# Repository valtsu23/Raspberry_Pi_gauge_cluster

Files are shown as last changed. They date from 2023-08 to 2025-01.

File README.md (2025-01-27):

# Raspberry_Pi_gauge_cluster
### Check out also new improved version: https://github.com/valtsu23/DIY-Emu-Black-Dash



Video: https://youtu.be/ISC5q4k9wDg

### Updates
30.8.2023 display_v2.py released (more info on the file)

### How it works
Adafruit Feather receives messages from Can Bus and picks rpm signal for shift light. Feather sends same can bus data bytes over Uart to Raspberry pi. 
Feather reads the amount of ambient light from photodiode and controls screeen brightness with pwm. 
Device needs switched 12V and continous 12v from battery to work correctly. Switched power wakes up the device and Raspberry pi starts booting. When Can Bus stream is lost Raspberry pi automatically starts shutdown process and sends message to Feather. After specified time the Feather turns off the relay connected to continous 12v and cuts power from the device. The device doesn't consume any power after shutdown. 

### Something to improve
- More testing needed
- Adding Raspberry pi setup guide
- Shortening the start up time (about 25 seconds now)

### Technical specs:
- Raspberry Pi 4 Model B 4GB
- SanDisk Extreme Pro UHS-I U3 64GB microSD
- 5" sunlight readable display with touchscreen from Makerplane:
  - https://store.makerplane.org/5-sunlight-readable-touchscreen-hdmi-display-for-raspberry-pi/
- DIY PCB inside the enclosure controls power for all devices and receives Can Bus messages and sends them over UART to Raspberry pi
  - DC-DC converter
  - Adafruit Feather M4 CAN Express with ATSAME51
  - Adafruit DS3231 Precision RTC - STEMMA QT
  - Screen brightness control
  - Adafruit Neopixel shiftlight control
  - Small relay for power

### Software specs
- Raspberry Pi OS Lite 64bit (bullseye)
  - X server: X.Org
  - Window manager: Openbox
  - Gauge cluster software is based on Pygame graphics library
### Graphic software functions
- There is 6 sensors data (3 left and 3 right) that you can choose to display with touscreen
- bar on the bottom of the screen in normal situation is blue and shows Raspberry pi CPU temperature
- If there is some error detected by ECU or battery voltage is low. Error flags are shown on the bottom of the screen and the bar is red
  
### Can bus data
- Most of the data needed is read from Ecumaster Emu Black can stream
- There is also DIY can bus device sending message id 0x400, which contains
  - Turn signals
  - High beam on
  - Fuel level
  - Ambient temperature

### Case
- Designed with FreeCAD
- Filament is PETG
- M3x6 machine screws 2 pcs
- M4 thread insert 1 pcs
- M4x8 machine screw 1pcs
- M4x20 machine screw 2pcs
- M4 nut 2pcs

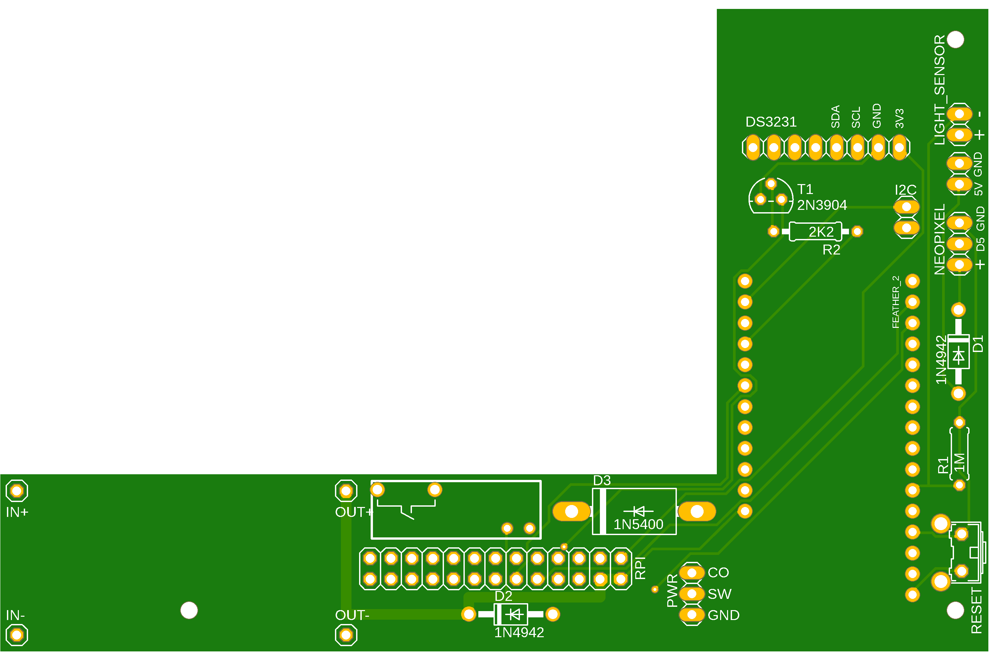
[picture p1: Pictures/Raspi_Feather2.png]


### Part list for PCB:
#### From www.partco.fi
  - PCH2596S DC-DC converter (LM2596S)
  - 3A diode 
  - 1A diode 2pcs
  - FTR-F3AA005V (small 5V relay)
  - BPW42 3mm phototransistor or similar
  - 2N3904 NPN transistor or similar
  - B3F-31XX Omron switch or SKH KKK 2 from partco.fi
  - 2k2 0,6w resistor
  - 1M 0,6w resistor 
  - 2x13 male pin header with long pins (20mm total length)
  - 2x13 female smd pin header (soldered to display pcb)
  - 1x40 female pin header
  - 1x40 male pin header
  - 0,22mm2 - 0,5mm2 wires (0,5mm2 recommended for power and ground)
#### From Berrybase.de
  - NeoPixel Stick mit 8 WS2812 5050 RGB LEDs (Copy of Adafruit's product. Dimensions won't match)
#### From www.adafruit.com
  - Adafruit DS3231 Precision RTC - STEMMA QT
  - Adafruit Feather M4 CAN Express with ATSAME51
#### From www.ebay.com
  - 5pin JST-SM connector pair



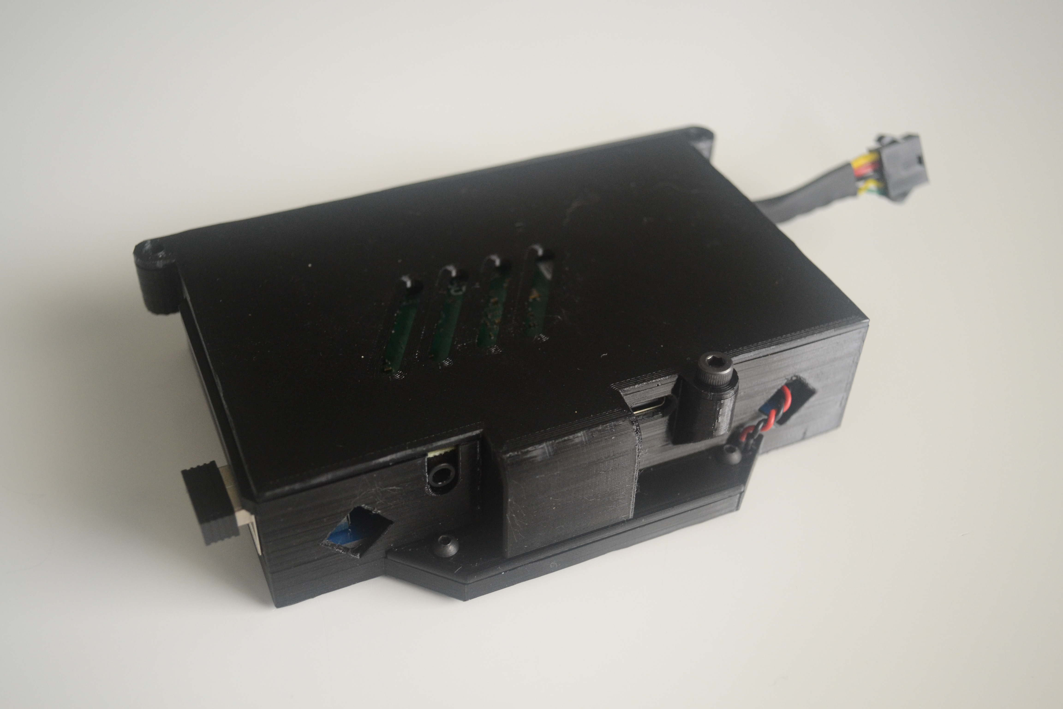
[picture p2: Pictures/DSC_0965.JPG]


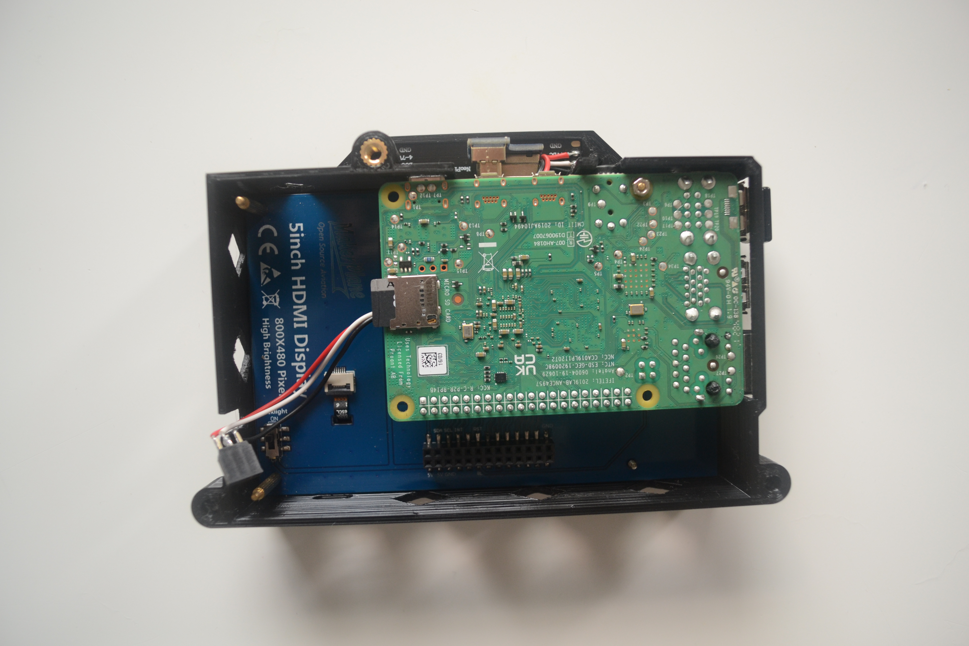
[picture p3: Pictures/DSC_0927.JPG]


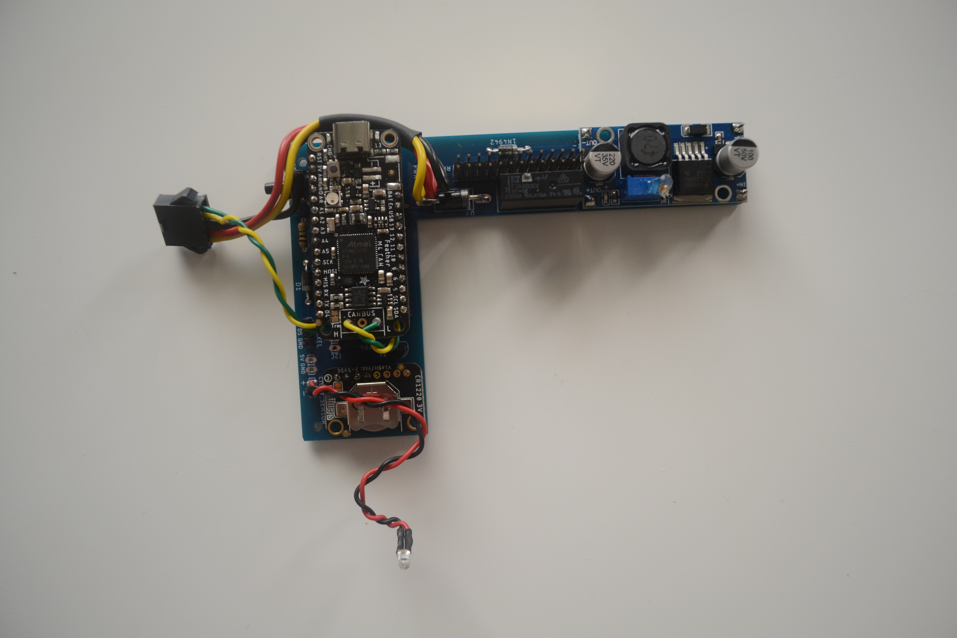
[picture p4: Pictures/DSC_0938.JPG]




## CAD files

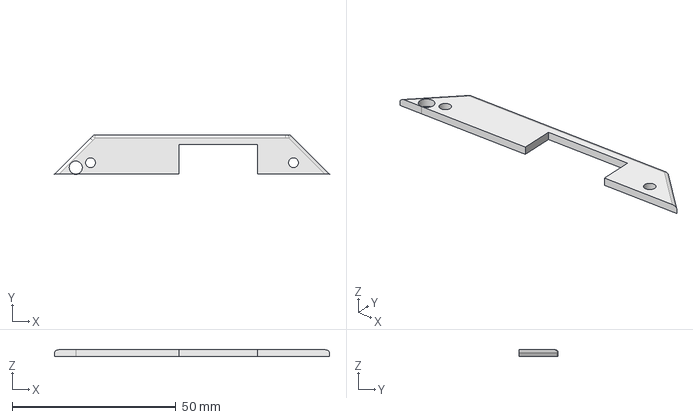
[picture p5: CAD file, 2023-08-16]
Case/Neopixel_back.FCStd
84.0 x 12.0 x 2.00 mm

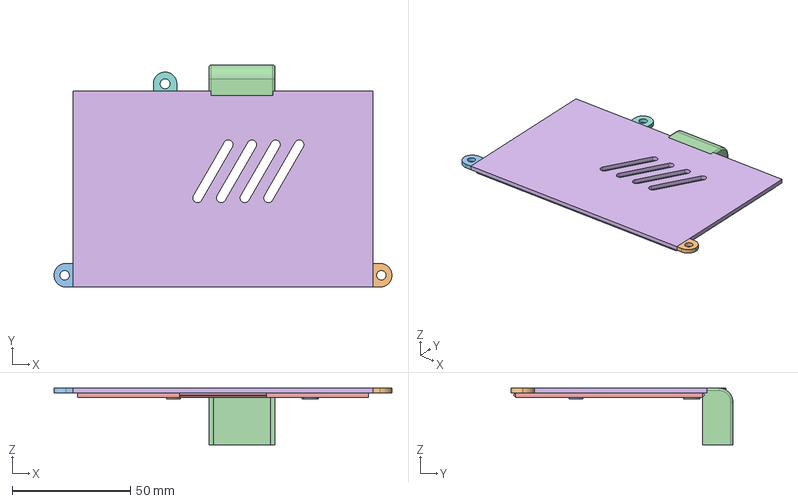
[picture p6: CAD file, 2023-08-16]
Case/Back.FCStd
143.0 x 94.0 x 24.0 mm
Tube002
Tube003
Tube
Tube001

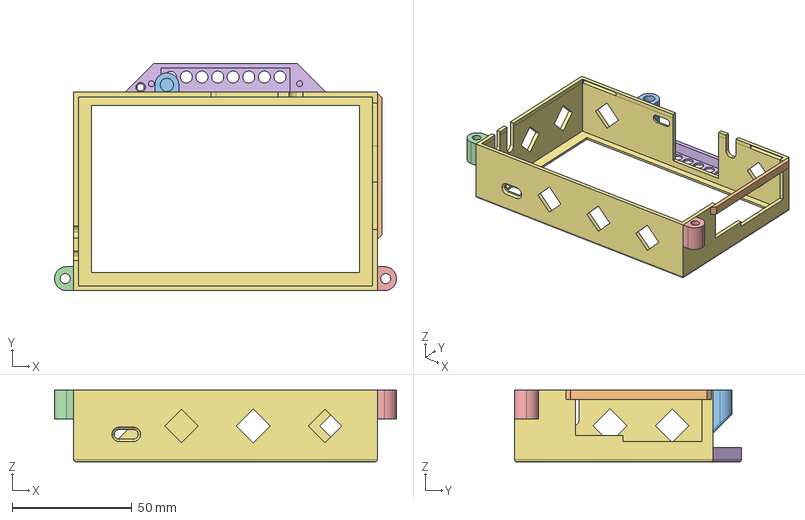
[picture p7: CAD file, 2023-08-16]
Case/Face.FCStd
143.0 x 95.0 x 30.0 mm
Kuutio014

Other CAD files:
Case/Neopixel.stl
Case/Back.stl
Case/Face.stl

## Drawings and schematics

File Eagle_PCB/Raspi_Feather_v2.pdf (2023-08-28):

SpiceOrder 1 | SpiceOrder 2 | SpiceOrder 1 SpiceOrder 2

# T1 R²

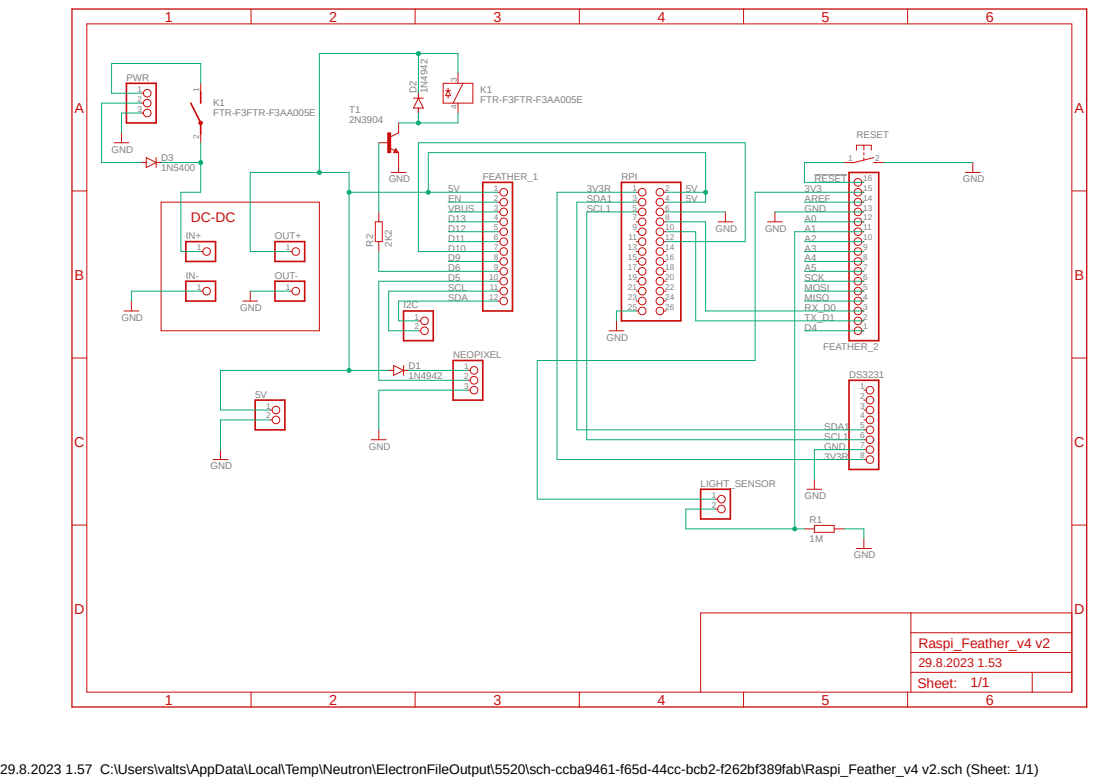
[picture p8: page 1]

29.8.2023 1.57 C:\Users\valts\AppData\Local\Temp\Neutron\ElectronFileOutput\5520\sch-ccba9461-f65d-44cc-bcb2-f262bf389fab\Raspi_Feather_v4 v2.sch (Sheet: 1/1)

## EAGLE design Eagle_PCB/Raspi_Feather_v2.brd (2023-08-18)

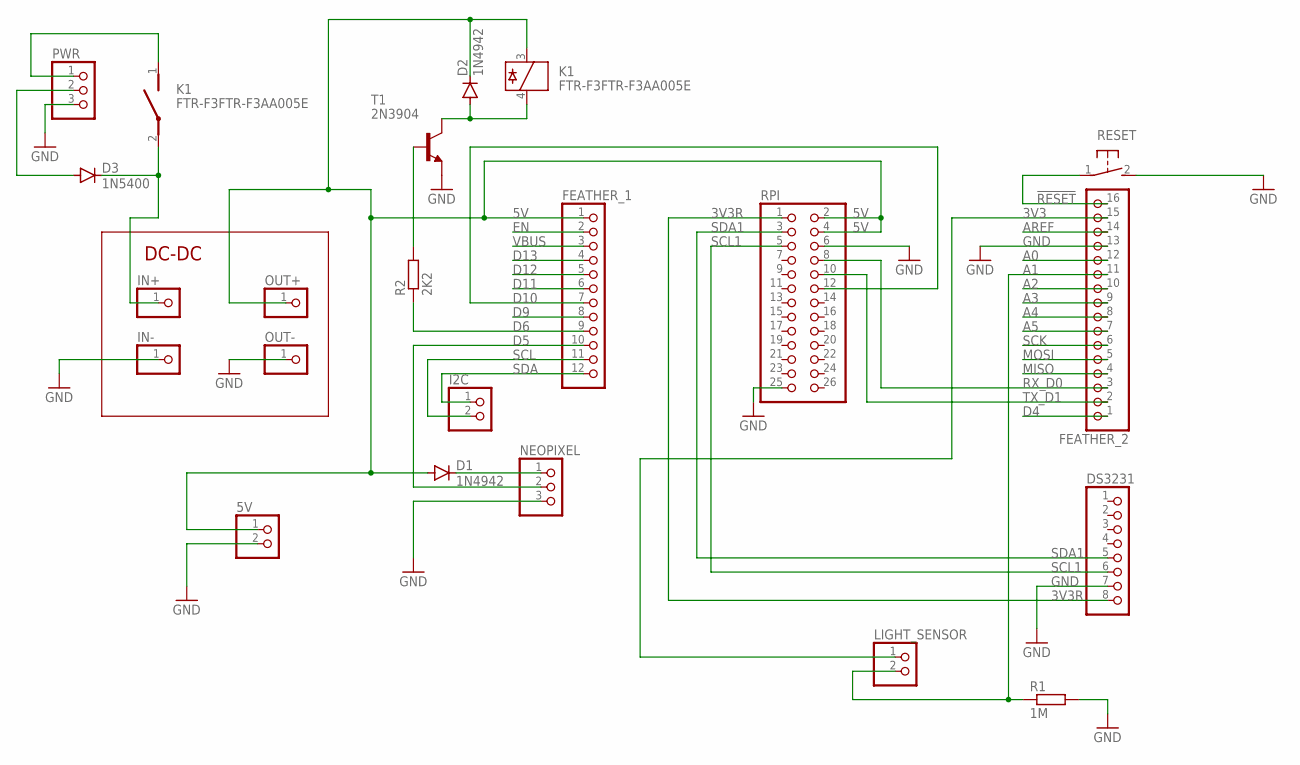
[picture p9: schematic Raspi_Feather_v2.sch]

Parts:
5V: PINHD-1X2; 1X02
D1, D2: 1N4942; DO41-10
D3: 1N5400; DO201-15
DS3231: PINHD-1X8; 1X08
FEATHER_1: HEADER-1X12; 1X12_ROUND
FEATHER_2: HEADER-1X16ROUND; 1X16_ROUND
I2C: PINHD-1X2; 1X02
IN+: PINHD-1X1; 1X01
IN-: PINHD-1X1; 1X01
K1: FTR-F3FTR-F3AA005E; REED
LIGHT_SENSOR: PINHD-1X2; 1X02
NEOPIXEL: PINHD-1X3; 1X03
OUT+: PINHD-1X1; 1X01
OUT-: PINHD-1X1; 1X01
PWR: PINHD-1X3; 1X03
R1: 1M; 0207/7
R2: 2K2; 0207/10
RESET: 31-XX; B3F-31XX
RPI: PINHD-2X13; 2X13
T1: 2N3904; TO92

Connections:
3V3: FEATHER_2.15, LIGHT_SENSOR.1
3V3R: DS3231.8, RPI.1
5V: 5V.1, D1.A, D2.C, FEATHER_1.1, K1.3, OUT+.1, RPI.2, RPI.4
!RESET: FEATHER_2.16, RESET.1
A0: FEATHER_2.12
A1: FEATHER_2.11, LIGHT_SENSOR.2, R1.1
A2: FEATHER_2.10
A3: FEATHER_2.9
A4: FEATHER_2.8
A5: FEATHER_2.7
AREF: FEATHER_2.14
D4: FEATHER_2.1
D5: FEATHER_1.10, NEOPIXEL.2
D6: FEATHER_1.9, R2.1
D9: FEATHER_1.8
D10: FEATHER_1.7, RPI.12
D11: FEATHER_1.6
D12: FEATHER_1.5
D13: FEATHER_1.4
EN: FEATHER_1.2
GND: 5V.2, DS3231.7, FEATHER_2.13, IN-.1, NEOPIXEL.3, OUT-.1, PWR.3, R1.2, RESET.2 (S), RPI.6, RPI.25, T1.3 (E)
IN+: D3.C, IN+.1, K1.2
IN_CO: K1.1, PWR.1
IN_SW: D3.A, PWR.2
MISO: FEATHER_2.4
MOSI: FEATHER_2.5
unnamed: D1.C, NEOPIXEL.1
unnamed: R2.2, T1.2 (B)
unnamed: D2.A, K1.4, T1.1 (C)
RX_D0: FEATHER_2.3, RPI.8
SCK: FEATHER_2.6
SCL: FEATHER_1.11, I2C.2
SCL1: DS3231.6, RPI.5
SDA: FEATHER_1.12, I2C.1
SDA1: DS3231.5, RPI.3
TX_D1: FEATHER_2.2, RPI.10
VBUS: FEATHER_1.3

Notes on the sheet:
DC-DC

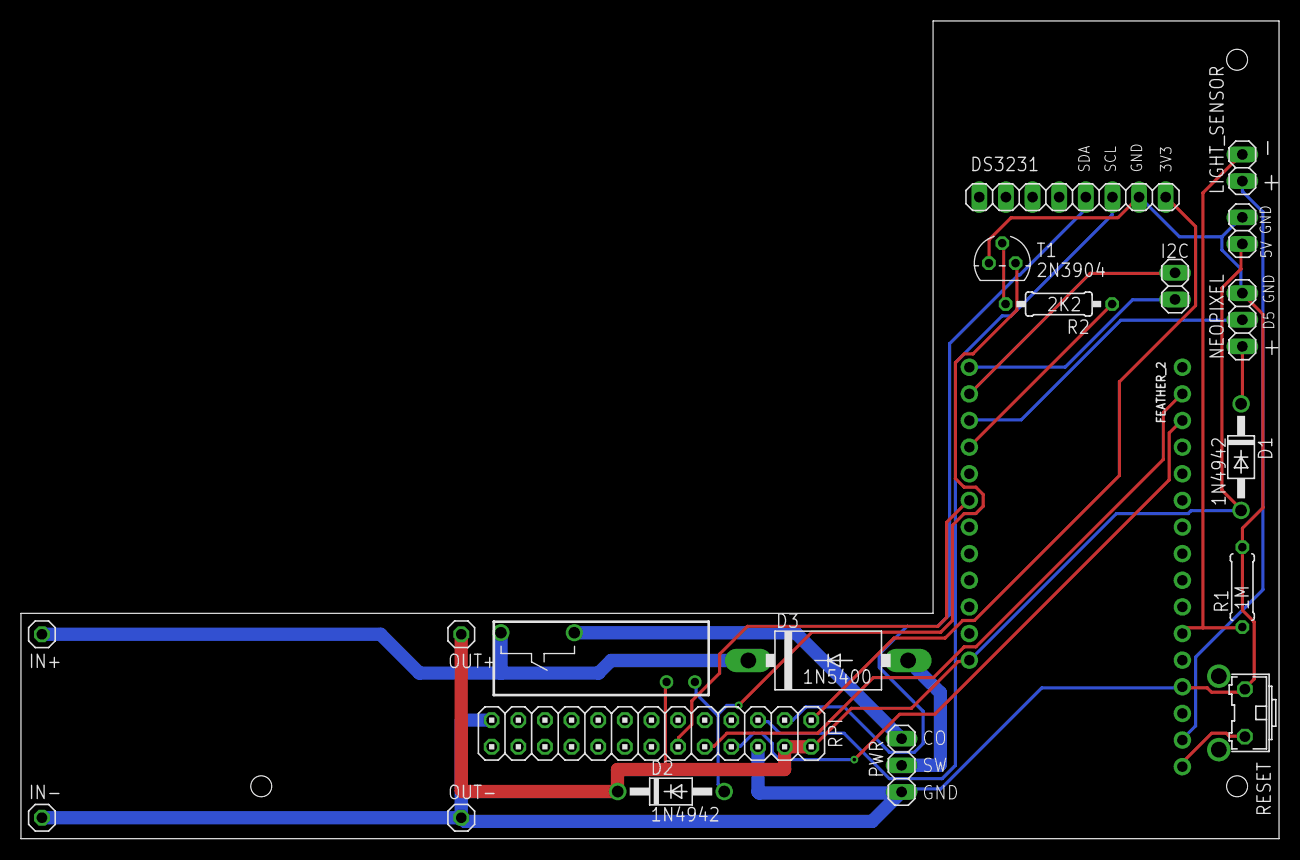
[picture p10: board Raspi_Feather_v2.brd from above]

Board: 2 copper layers, 120.0 x 78.0 mm, 21 parts (0 on the bottom side), 21 nets.

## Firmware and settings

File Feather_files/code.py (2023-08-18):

import busio
import board
import digitalio
import time
import canio
import struct
import analogio
import pwmio
import shift_light_v2
from digitalio import DigitalInOut, Direction

# Constants
MSG_START = b'\xff\xff'
ECU_CAN_ID = 0x600

# Shift light
# SETUP
END = 8600
STEP = 150

# Make sure the leds are off
shift_light_v2.leds_off()

# Screen backlight brightness control
backlight = pwmio.PWMOut(board.D10, frequency=5000, duty_cycle=0)

# Light sensor
ADC = analogio.AnalogIn(board.A1)
def is_dark():
    a_val = ADC.value
    # print(a_val)
    if a_val < 6000:
        return True
    else:
        return False

# Dimmer
def dimmer(value):
    global led_br
    # Dark
    if value is True:
        backlight.duty_cycle = 30_000
        led_br = 10
    # Bright
    else:
        backlight.duty_cycle = 0
        led_br = 80

# Run at startup
dimmer(is_dark())

uart = busio.UART(board.TX, board.RX, baudrate=576_000, timeout=.5)

relay = DigitalInOut(board.D6)
relay.direction = Direction.OUTPUT
relay.value = True

# CAN BUS
# The CAN transceiver has a standby pin, bring it out of standby mode
if hasattr(board, 'CAN_STANDBY'):
    standby = digitalio.DigitalInOut(board.CAN_STANDBY)
    standby.switch_to_output(False)

# The CAN transceiver is powered by a boost converter, turn on its supply
if hasattr(board, 'BOOST_ENABLE'):
    boost_enable = digitalio.DigitalInOut(board.BOOST_ENABLE)
    boost_enable.switch_to_output(True)

# Can Bus pins
can = canio.CAN(rx=board.CAN_RX, tx=board.CAN_TX, baudrate=500_000, auto_restart=True)

# CAN listener 0x400-0x407 and 0x600-0x607
listener = can.listen(matches=[canio.Match(id=0x607, mask=0x5F8)], timeout=.5)

# Variables
old_bus_state = None
fail_safe = 0
counter = 0
counter_start = False
old_dark = is_dark()
dim_counter = 0
t1 = time.monotonic()
shift_light_off = False
rpm = 0

# Debug
# rpm = 7999

while True:
    """
    # Debug
    # id = struct.pack("H", 0x600)
    id = 0x600
    data = struct.pack("<HBbHH", rpm, 0, 25, 100, 50)
    # time.sleep(.01)
    """

    # CAN BUS
    # Bus state information
    bus_state = can.state
    if bus_state != old_bus_state:
        print(f"Bus state changed to {bus_state}")
        old_bus_state = bus_state
    message = listener.receive()

    # Turn off when needed
    if message is None:
        print("No message received within timeout")
        serial_read = uart.read(1)
        # Shutdown message from Raspberry pi
        if serial_read == b'\xff':
            counter_start = True
            print("Counter start")
        if counter_start is True:
            counter += 1
        # Failsafe if message receiving failed
        fail_safe += 1
        if counter > 10 or fail_safe > 60:
            print("Shutting down")
            relay.value = False
        continue

    counter = 0
    fail_safe = 0
    counter_start = False

    id = message.id
    data = message.data

    # Reading rpm for shift light
    if id == ECU_CAN_ID:
        # Unpack message
        message = struct.unpack("<HBbHH", data)
        rpm = message[0]

    # print("Received a message with id:", (hex(id)))
    id_packed = struct.pack("H", id)

    # ECU_CAN_ID + 1 message not needed
    if id != ECU_CAN_ID + 1:
        # Send start message, id and message
        uart.write(MSG_START)
        uart.write(id_packed)
        uart.write(data)

    # Shift light
    if rpm > END - STEP * 5:
        shift_light_v2.action(rpm, STEP, END, led_br)
        shift_light_off = False
        # Make sure all leds are off
    else:
        if shift_light_off is False:
            shift_light_v2.leds_off()
            shift_light_off = True

    # Dimmer
    dark = is_dark()

    # If ambient light hasn't changed: reset timer
    if dark is old_dark:
        t1 = time.monotonic()

    # If timer hasn't been reseted in 4 seconds: change brightness
    if time.monotonic() > t1 + 4:
        dimmer(dark)
        old_dark = dark

   """
    # Debug
    # print("rpm =", rpm)
    rpm = int(rpm)
    if rpm < 8000:
        rise_rpm = True
    elif rpm > 9300:
        rise_rpm = False

    if rise_rpm is True:
        rpm += 1
    else:
        rpm -= 1
    time.sleep(.00625)
    """

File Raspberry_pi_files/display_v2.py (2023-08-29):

# Version 2
# Biggest change is updating screen only where it's required using display.update.
# This helps with cpu load and cpu temperature.

import pygame
import time
import serial
import struct
import os

# Uart setup
uart = serial.Serial("/dev/ttyAMA0", baudrate=576_000, timeout=1,
                     parity=serial.PARITY_ODD)

# PyGame
size = width, height = (800, 480)
pygame.init()
screen = pygame.display.set_mode(size, pygame.FULLSCREEN)
pygame.mouse.set_visible(False)

# Read needed files
path = "/home/valtteri/EMUB/"
units_memory = open(path + "units_memory.txt", "r")
units = units_memory.read().splitlines()
units_memory.close()
odometer_memory = open(path + "odometer_memory.txt", "r")
odometer = float(odometer_memory.readline())
odometer_memory.close()

# Variables
start_up = True
timeout_counter = 0
rpm = 0
speed = 0
gear = 0
out_temp = 0
fuel_level = None
raw_fuel_level = 0
batt_v = 0
left_blinker = False
right_blinker = False
high_beam = False
errors = 0
speed_sum = 0
speed_sum_counter = 0
distance_timer = time.monotonic()
old_rpm = None
old_gear = None
old_speed = None
old_out_temp = None
old_odometer = None
old_clock = None
old_error_list = None
old_refuel = None
old_right_blinker = None
old_left_blinker = None
old_high_beam = None
old_values = [None, None, None, None, None, None]
values = [0, 0, 0, 0, 0, 0]
clear = True
loop = True
touch = False
start = True
timeout_counter = 0
filter_counter = 0
filter_sum = 0
countdown = 10
buffer_empty = True
old_cpu_temp = None
cpu_timer = time.monotonic()

# CONSTANTS
CENTER_X, CENTER_Y = (width / 2, height / 2)
RIGHT_SIDE = width - 180
RED = (155, 0, 0)
WHITE = (255, 255, 255)
DARK_BLUE = (0, 64, 128)
LIGHT_BLUE = (0, 128, 255)
GREEN = (0, 255, 0)
BLACK = (0, 0, 0)
ECU_CAN_ID = 0x600
FUEL_MAX = 197
FUEL_MIN = 37

# Odometer calculations and file save
def odometer_save(speed_sum, speed_sum_counter, distance_timer, odometer, path):
    if speed_sum == 0:
        return odometer
    average_speed = (speed_sum / speed_sum_counter) * 0.27777778
    timer = time.monotonic() - distance_timer
    distance = (average_speed * timer) / 1000
    odometer = odometer + distance
    # Saving to memory
    odometer_memory = open(path + "odometer_memory.txt", "w")
    odometer_memory.write(str(odometer))
    odometer_memory.close()
    return odometer

def menu():
    screen.fill((60, 60, 60))
    font_20 = pygame.font.SysFont("dejavusans", 20)

    # Constants
    WHITE = (255, 255, 255)
    BLACK = (0, 0, 0)

    def create_rect(x, y, text):
        pygame.draw.rect(screen, BLACK, [x, y, 190, 70], border_radius=10)
        name = font_20.render(text, True, WHITE)
        screen.blit(name, (x + 15, y + 20))
        return pygame.Rect(x, y, 190, 70)

    # Coordinates
    coordinates_x = []
    coordinates_y = []
    coordinate_y = 5
    coordinate_x = 5
    for x in range(6):
        coordinates_y.append(coordinate_y)
        coordinate_y += 80
    for x in range(4):
        coordinates_x.append(coordinate_x)
        coordinate_x += 200

    touch = False

    # Buttons
    rpm_button = create_rect(coordinates_x[0], coordinates_y[0], "RPM")
    tps_button = create_rect(coordinates_x[1], coordinates_y[0], "TPS")
    iat_button = create_rect(coordinates_x[2], coordinates_y[0], "IAT")
    map_button = create_rect(coordinates_x[3], coordinates_y[0], "MAP")
    inj_pw_button = create_rect(coordinates_x[0], coordinates_y[1], "Inj pw.")
    oil_t_button = create_rect(coordinates_x[1], coordinates_y[1], "Oil temp.")
    oil_p_button = create_rect(coordinates_x[2], coordinates_y[1], "Oil pressure")
    fuel_p_button = create_rect(coordinates_x[3], coordinates_y[1], "Fuel pressure")
    clt_t_button = create_rect(coordinates_x[0], coordinates_y[2], "Coolant temp.")
    ign_ang_button = create_rect(coordinates_x[1], coordinates_y[2], "Ignition angle")
    dwell_button = create_rect(coordinates_x[2], coordinates_y[2], "Dwell time")
    lambda_button = create_rect(coordinates_x[3], coordinates_y[2], "Lambda")
    lambda_corr_button = create_rect(coordinates_x[0], coordinates_y[3], "Lambda corr.")
    egt_1_button = create_rect(coordinates_x[1], coordinates_y[3], "EGT 1")
    egt_2_button = create_rect(coordinates_x[2], coordinates_y[3], "EGT 2")
    batt_button = create_rect(coordinates_x[3], coordinates_y[3], "Battery voltage")
    ethanol_ctnt_button = create_rect(coordinates_x[0], coordinates_y[4], "Ethanol content")
    dbw_pos_button = create_rect(coordinates_x[1], coordinates_y[4], "Dbw position")
    boost_t_button = create_rect(coordinates_x[2], coordinates_y[4], "Boost target")
    dsg_m_button = create_rect(coordinates_x[3], coordinates_y[4], "DSG Mode")
    lambda_t_button = create_rect(coordinates_x[0], coordinates_y[5], "Lambda target")
    fuel_used_button = create_rect(coordinates_x[1], coordinates_y[5], "Fuel used")
    fuel_level_button = create_rect(coordinates_x[2], coordinates_y[5], "Fuel level")
    empty_button = create_rect(coordinates_x[3], coordinates_y[5], "")

    # Display refresh
    pygame.display.flip()

    while True:
        for event in pygame.event.get():
            # Unit selection
            if event.type == pygame.MOUSEBUTTONDOWN:
                touch = True
                pos = event.pos
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

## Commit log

2023-08-16 Update code.py
    fail_safe 30 -> 60
    [code.py]
2023-08-18 Photodiode pull down resistor changed
    From 150k -> 1M, for better adc scale
    [Raspi_Feather_v2.brd, Raspi_Feather_v2.sch]
2023-08-18 Update README.md
    Photodiode pull down resistor changed from 150k -> 1M, for better adc scale.
2023-08-18 Update code.py
    Photodiode pull down resistor has changed from 150k -> 1M, for better adc scale.

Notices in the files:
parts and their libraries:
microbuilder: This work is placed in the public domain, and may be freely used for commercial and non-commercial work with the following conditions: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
